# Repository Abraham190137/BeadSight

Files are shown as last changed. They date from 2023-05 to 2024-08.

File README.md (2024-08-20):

# BeadSight
This repo contains the code from the paper, "BeadSight: An Inexpensive Tactile Sensor Using Hydro-Gel Beads"

 - Unet_model.py: Pytorch implementation of the UNet model
 - raw_data_processing.py: Processes the video files, force data, and Gcode commands recorded by recording_main, converting the data into a hdf5 file.
 - model_training.py: Training and Testing of the BeadSight UNet model, using the recorded data.
 - model_eval.py: Functions for running inference on a dataset and printing/plotting the results.
 - inference.py: Code for implementing the trained UNet model (loaded from saved weights) to process images collected during robot operation.
 - defisheye.py: Helper script to undo the fish-eye effect of the bead-sight camera's lens.
 - data_loader.py: Dataset class, along with helper functions, for using the processed beadsight training data.

## Data Collection:
This folder contains all of the code used for data collection and processing. It contains:
 - Arduino code (in the Arduino folder) which was used to collect force data. Scale Data Reader.py is used to control the Arduino over serial link and to save the recorded forces and timestamps.
 - recording_main.py, which records video from the bead sight camera (USB camera), records the current force applied, measured by the Arduino and sent over a serial connection, and controls the 3D printer to execute presses, via commands sent over a serial connection.

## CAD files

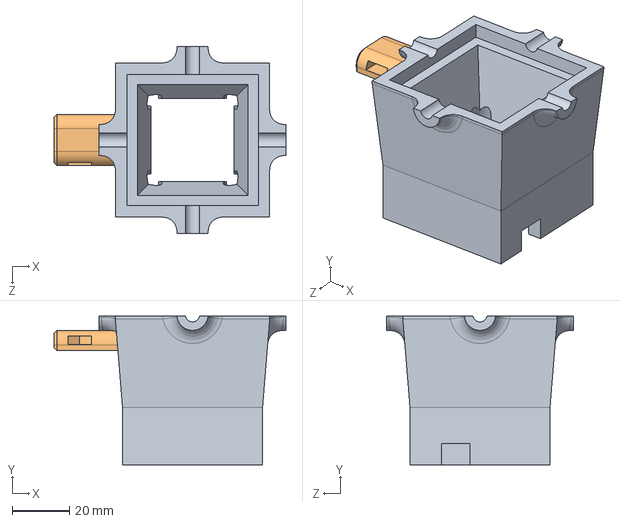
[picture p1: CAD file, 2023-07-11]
SolidWorks/Finger Attachement1.SLDASM
81.2 x 52.0 x 65.4 mm
Sensor Frame Fisheye Acrilic
franka_attachement

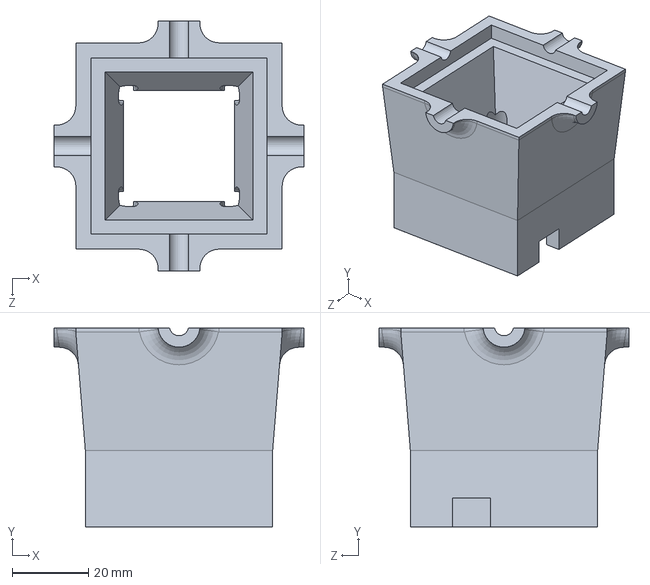
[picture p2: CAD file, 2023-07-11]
SolidWorks/Sensor Frame Fisheye Acrilic.SLDPRT
65.4 x 52.0 x 65.4 mm

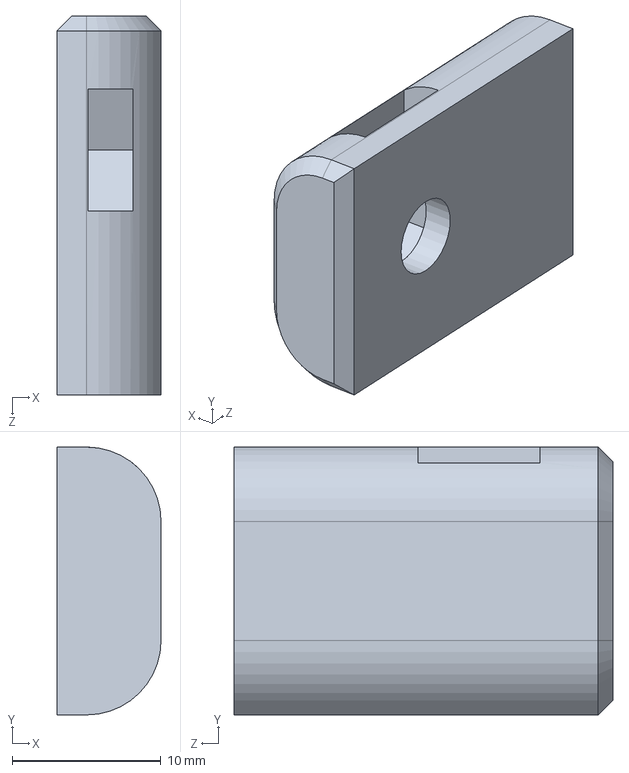
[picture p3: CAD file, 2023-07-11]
SolidWorks/franka_attachement.SLDPRT
7.00 x 18.0 x 25.5 mm

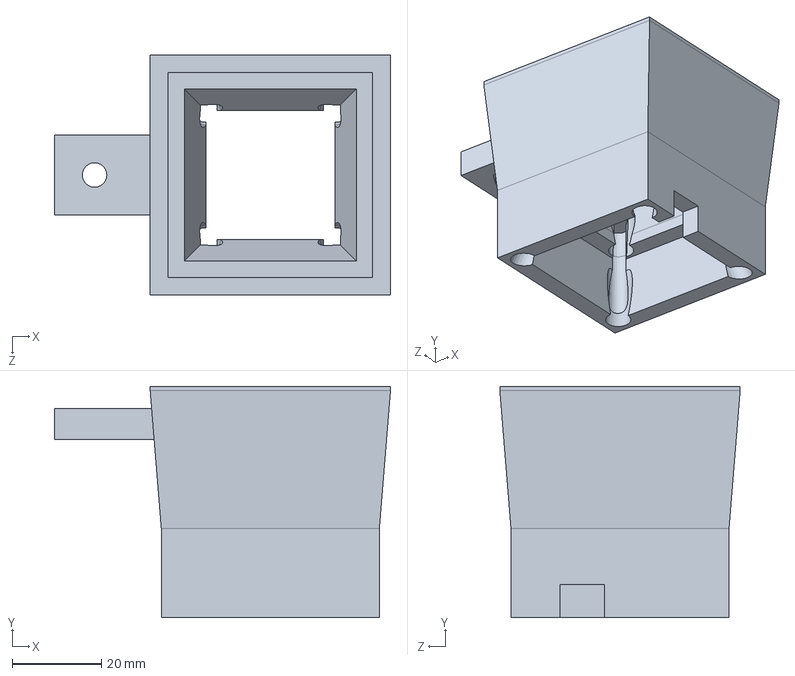
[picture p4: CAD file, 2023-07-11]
SolidWorks/Sensor Frame Fisheye Acrilic No Top Holes, Finger.SLDPRT
75.5 x 52.0 x 54.0 mm

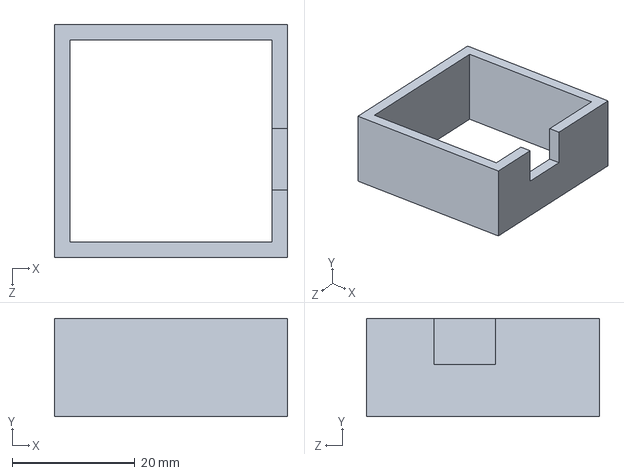
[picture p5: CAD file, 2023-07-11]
SolidWorks/Sensor Camera Holding Piece.SLDPRT
38.0 x 16.0 x 38.0 mm

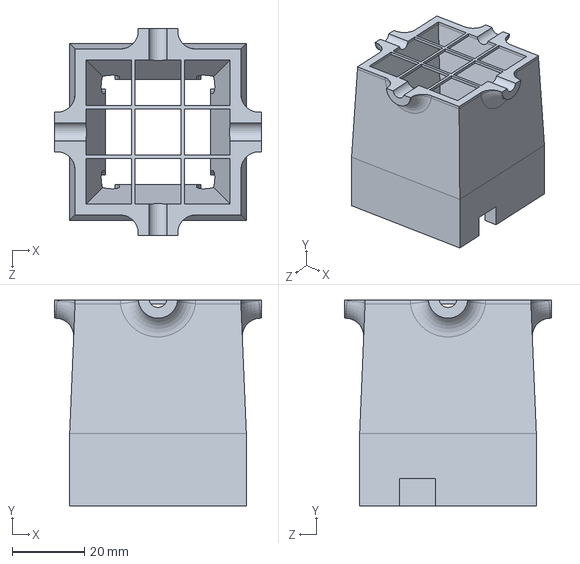
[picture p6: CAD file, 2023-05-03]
SolidWorks/Sensor Frame Fisheye2-40.SLDPRT
57.4 x 57.0 x 57.4 mm

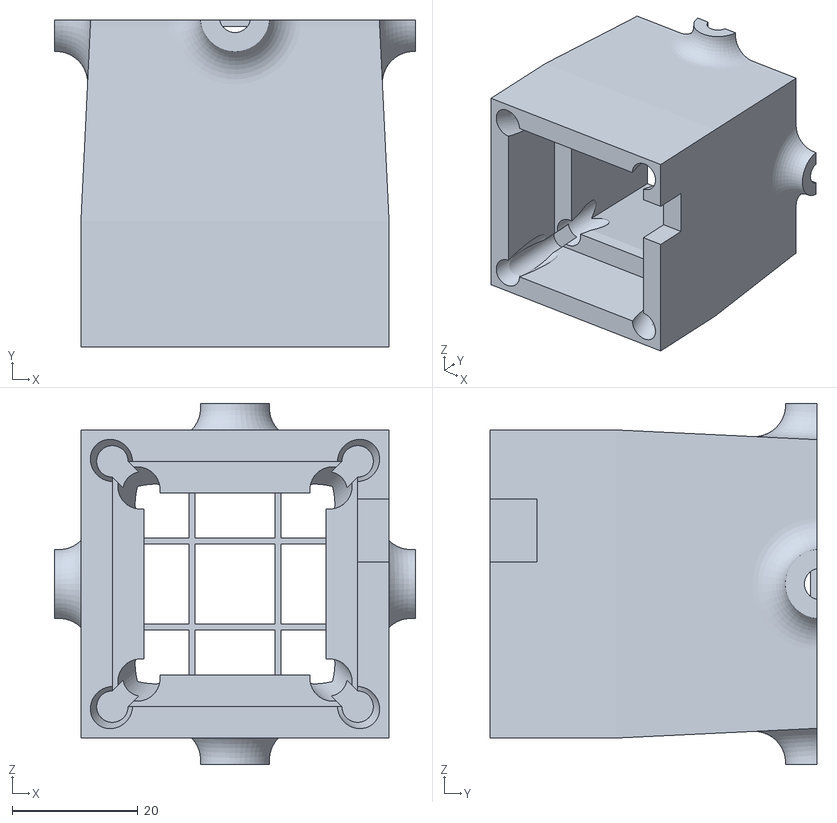
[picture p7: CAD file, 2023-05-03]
SolidWorks/Sensor Frame Fisheye2-35.STL
57.4 x 52.0 x 57.4

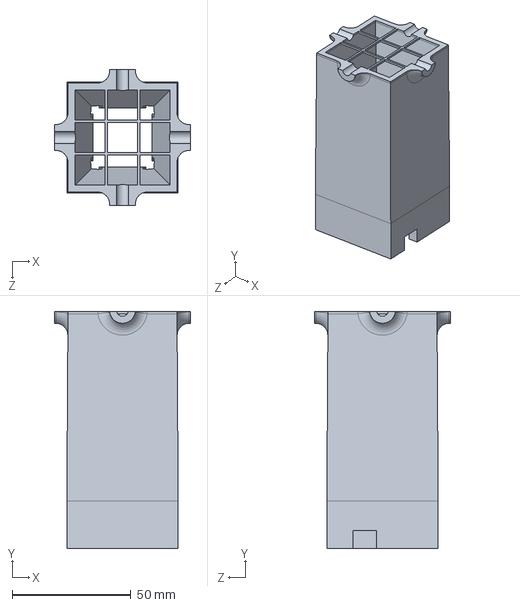
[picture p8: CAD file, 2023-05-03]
SolidWorks/Sensor Frame.SLDPRT
57.4 x 100.0 x 57.4 mm

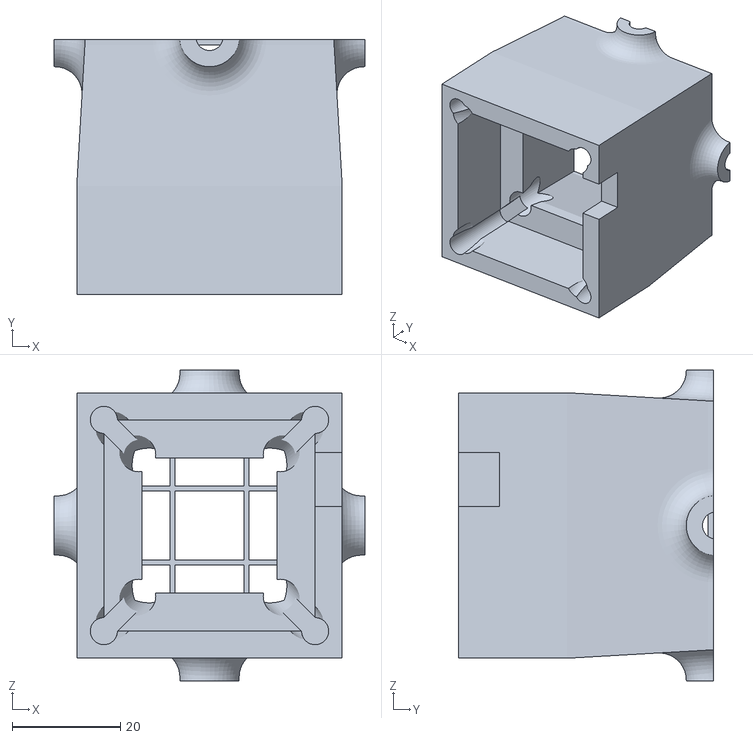
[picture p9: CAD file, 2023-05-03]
SolidWorks/Sensor Frame Fisheye - 30 cm.STL
57.4 x 47.0 x 57.4

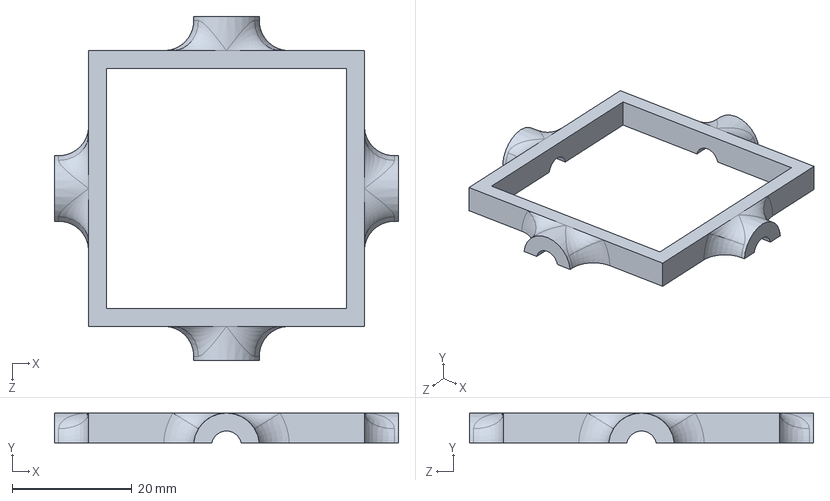
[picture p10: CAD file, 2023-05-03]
SolidWorks/Sensor top.SLDPRT
57.4 x 5.00 x 57.4 mm

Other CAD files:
SolidWorks/Sensor Frame Fisheye.SLDPRT
SolidWorks/Sensor Frame Fisheye2.SLDPRT
SolidWorks/Finger Attachement1.STL
SolidWorks/Sensor Camera Holding Piece.STL
SolidWorks/Sensor Frame Fisheye Acrilic No Top Holes, Finger.STL
SolidWorks/Sensor Frame Fisheye Acrilic.STL
SolidWorks/Sensor Frame Fisheye2-40.STL
SolidWorks/Sensor Frame Fisheye2.STL
SolidWorks/Sensor Frame.STL
SolidWorks/Sensor top.STL
SolidWorks/makeProjectedPlanarWire.x_t

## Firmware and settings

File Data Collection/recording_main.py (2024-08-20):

import cv2
import time
import os
import serial
from typing import List, Tuple
import numpy as np
import multiprocessing
import json


def video_logger(log_folder:str,
                 stop_event: multiprocessing.Event,
                 chunk_size:int=30*60*60, # save a new "chunk" every hour
                 height:int=1024,
                 width:int=1280,
                 fps:int=30,
                 debug_print:bool = False):

    # create the log folder
    frame_number = 0
    video_path = f"{log_folder}/video_{frame_number//chunk_size}.avi"
    log_path = f"{log_folder}/video_log_{frame_number//chunk_size}.txt"

    assert not os.path.exists(video_path), f"File already exists: {video_path}"
    assert not os.path.exists(log_path), f"File already exists: {log_path}"

    fourcc = cv2.VideoWriter_fourcc(*'XVID') # Using XVID codec for AVI format
    video_file = cv2.VideoWriter(video_path, fourcc, fps, (width, height))
    log_file = open(log_path, 'w')

    # Open the webcam
    cap = cv2.VideoCapture(0)

    cap.set(cv2.CAP_PROP_FRAME_WIDTH, width)
    cap.set(cv2.CAP_PROP_FRAME_HEIGHT, height)
    cap.set(cv2.CAP_PROP_FPS, fps)
    cap.set(cv2.CAP_PROP_FOURCC, cv2.VideoWriter_fourcc(*'MJPG'))

    previous_time = time.time()
    start_time = previous_time

    while not stop_event.is_set():
        # Read a frame from the webcam
        ret, frame = cap.read()
        cur_time = time.time()
        if not ret:
            break

        log_file.write(f"{cur_time},{frame_number},{video_path}\n")
        log_file.flush()
        video_file.write(frame)
        frame_number += 1
        
        if debug_print:
            print('\nframe_number:', frame_number)
            print('dt:', cur_time - previous_time)
            print('Avergae FPS:', frame_number / (cur_time - start_time))
            previous_time = cur_time
            print('frame shape:', frame.shape)

        if frame_number % chunk_size == 0:
            # save the video and log files
            video_file.release()
            log_file.close()
            video_path = f"{log_folder}/video_{frame_number//chunk_size}.avi"
            log_path = f"{log_folder}/video_log_{frame_number//chunk_size}.txt"
            assert not os.path.exists(video_path), f"File already exists: {video_path}"
            assert not os.path.exists(log_path), f"File already exists: {log_path}"
            video_file = cv2.VideoWriter(video_path, fourcc, fps, (width, height))
            log_file = open(log_path, 'w')

    # Release the webcam, video file, and log file
    cap.release()
    video_file.release()
    log_file.close()
    print('Video logger stopped successfully')


def force_logger(log_folder:str, 
                 stop_event: multiprocessing.Event,
                 serial_port:str = '/dev/ttyACM0'):

    assert os.path.exists(log_folder), f"Folder does not exist: {log_folder}"
    log_file = open(f"{log_folder}/force_log.txt", 'w') 
    last_read_time = time.time()   

    with serial.Serial(serial_port, 57600, timeout=2) as ser:
        start = False
        while not stop_event.is_set():
            if time.time()-last_read_time > 10:
                raise ValueError("No data read in 10 seconds")
            line = ser.readline()   # read a '\n' terminated line
            try:
                measurement = float(line.decode()[:-1])
            except:
                print("Error reading line:", line)
                continue
            cur_time = time.time()
            last_read_time = cur_time
            log_file.write(f"{cur_time},{measurement}\n")
            log_file.flush()
            
    log_file.close()
    print('Force logger stopped successfully')


class PrinterControl:
    def __init__(self, log_folder:str, serial_port:str) -> None:
        self.log_folder = log_folder
        self.log_file = open(f"{log_folder}/printer_log.txt", 'w')
        self.ser = serial.Serial(serial_port, 115200) 
        self.closed = False

    def send_command(self, command:str, rec_x:float=-1, rec_y:float=-1, delay:float=1):
        self.ser.write((command + "\n").encode())
        print(command)
        cur_time = time.time()
        self.log_file.write(f"{cur_time},{rec_x},{rec_y},{command}\r") # need to use \r, because the command can contain \n
        self.log_file.flush()
        time.sleep(delay)

    def close(self):
        self.ser.close()
        self.log_file.close()
        self.closed = True

    def __del__(self):
        if not self.closed:
            self.close()

# message for one press action
def press_message(x_loc: float, y_loc: float, z_down:float, z_up:float):
    return f"G0 X{x_loc} Y{y_loc} Z{z_up} F700; move to position\n" + \
           f"G0 X{x_loc} Y{y_loc} Z{z_down} F200; press\n" + \
           "G04 P1000; pause\n" + \
           f"G0 X{x_loc} Y{y_loc} Z{z_up} F700; release"

def run_exeriment(log_folder:str, 
                  run_time:float,
                  x_range:Tuple[float, float],
                  y_range:Tuple[float, float],
                  z_range:Tuple[float, float],
                  z_clear:float = 160):

    # initalize the loggers:
    stop_event = multiprocessing.Event()
    video_logger_process = multiprocessing.Process(target=video_logger, args=(log_folder, stop_event), daemon=True)
    video_logger_process.start()
    force_logger_process = multiprocessing.Process(target=force_logger, args=(log_folder, stop_event), daemon=True)
    force_logger_process.start()
    printer = PrinterControl(log_folder, '/dev/ttyUSB0')

    try:
        # initalize the printer:
        printer.send_command("M140 S0 T0; set temp of bed", delay = 1)
        printer.send_command("M104 S0 T0; set temp of extruder 1", delay = 1)
        printer.send_command("M104 S0 T1; set temp of extruder 2", delay = 1)
        printer.send_command("G90; use absolute positioning", delay = 1)
        printer.send_command("G28; home all axes", delay = 45)
        printer.send_command(f"G0 X0 Y0 Z{z_clear} F700; move to clear position", delay = 30)
        printer.send_command(f"G0 X{x_range[0]-10} Y{y_range[0]-10} Z{z_clear} F700; calibration motion", delay = 30)

        calib_offset = 10
        # Calibaration presses:
        for x_pos, y_pos in [(x_range[0]-calib_offset, y_range[0]-calib_offset), (x_range[0]-calib_offset, y_range[1]+calib_offset), (x_range[1]+calib_offset, y_range[0]-calib_offset), (x_range[1]+calib_offset, y_range[1]+calib_offset)]:
            printer.send_command(press_message(x_pos, y_pos, z_range[0], z_clear), -1, -1, 15)

        for x_pos, y_pos in [(x_range[0], y_range[0]), (x_range[0], y_range[1]), (x_range[1], y_range[0]), (x_range[1], y_range[1])]:
            printer.send_command(press_message(x_pos, y_pos, z_range[0], z_clear), -1, -1, 15)

        # begin the real testing:
        start_time = time.time()
        press_num = 0
        while time.time() - start_time < run_time:
            x_pos = np.random.uniform(x_range[0], x_range[1])
            y_pos = np.random.uniform(y_range[0], y_range[1])
            z_pos = np.random.uniform(z_range[0], z_range[1])

            printer.send_command(press_message(x_pos, y_pos, z_pos, z_clear), x_pos, y_pos, 10)

        print("Experiment completed successfully")

    except:
        print("An error occured, stopping the experiment")

    stop_event.set()
    video_logger_process.join()
    force_logger_process.join()
    printer.close()

if __name__ == "__main__":
    save_dir = "Data Collection/data"
    save_name = "5 hr data collection - 100 my bag"
    run_time = 5*60*60 # number of seconds to run for.
    center = (151.8, 108.9)
    radius = 13.75
    x_range = (center[0] - radius, center[0] + radius)
    y_range = (center[1] - radius, center[1] + radius)
    z_range = (127, 128)
    z_clear = 137.5

    n = 0
    while os.path.exists(f"{save_dir}/{save_name}_{n}"):
        n += 1
    folder_name = f"{save_dir}/{save_name}_{n}"
    os.mkdir(folder_name)

    # save parametes in json file:
    meta_data = {
        "resolution": (256, 256),
        "fps": 30,
        "contact_radius": 6.25,
        "sensor_size": (41, 41),
        "force_unit": "g",
        "dist_unit": "mm",
        "run_time": run_time,
        "center": center,
        "radius": radius,
        "x_range": x_range, 
        "y_range": y_range, 
        "z_range": z_range, 
        "z_clear": z_clear
    }

    with open(f"{folder_name}/experiment_parameters.json", 'w') as f:
        json.dump(meta_data, f)

    run_exeriment(log_folder=folder_name,
                  run_time=run_time,
                  x_range=x_range,
                  y_range=y_range,
                  z_range=z_range,
                  z_clear=z_clear)
    

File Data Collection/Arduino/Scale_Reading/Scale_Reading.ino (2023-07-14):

/**
 * Complete project details at https://RandomNerdTutorials.com/arduino-load-cell-hx711/
 *
 * HX711 library for Arduino - example file
 * https://github.com/bogde/HX711
 *
 * MIT License
 * (c) 2018 Bogdan Necula
 *
**/

#include <Arduino.h>
#include "HX711.h"

// HX711 circuit wiring
const int LOADCELL_DOUT_PIN = 2;
const int LOADCELL_SCK_PIN = 3;
const float calibration = 465.0;

HX711 scale;

void setup() {
  pinMode(7, OUTPUT); 
  Serial.begin(57600);
  // Serial.println("HX711 Demo");
  // Serial.println("Initializing the scale");

  scale.begin(LOADCELL_DOUT_PIN, LOADCELL_SCK_PIN);

  // Serial.println("Before setting up the scale:");
  // Serial.print("read: \t\t");
  // Serial.println(scale.read());      // print a raw reading from the ADC

  // Serial.print("read average: \t\t");
  // Serial.println(scale.read_average(20));   // print the average of 20 readings from the ADC

  // Serial.print("get value: \t\t");
  // Serial.println(scale.get_value(5));   // print the average of 5 readings from the ADC minus the tare weight (not set yet)

  // Serial.print("get units: \t\t");
  // Serial.println(scale.get_units(5), 1);  // print the average of 5 readings from the ADC minus tare weight (not set) divided
  //           // by the SCALE parameter (not set yet)
            
  scale.set_scale(calibration);    // this value is obtained by calibrating the scale with known weights; see the README for details
  scale.tare();               // reset the scale to 0

  // Serial.println("After setting up the scale:");

  // Serial.print("read: \t\t");
  // Serial.println(scale.read());                 // print a raw reading from the ADC

  // Serial.print("read average: \t\t");
  // Serial.println(scale.read_average(20));       // print the average of 20 readings from the ADC

  // Serial.print("get value: \t\t");
  // Serial.println(scale.get_value(5));   // print the average of 5 readings from the ADC minus the tare weight, set with tare()

  // Serial.print("get units: \t\t");
  // Serial.println(scale.get_units(5), 1);        // print the average of 5 readings from the ADC minus tare weight, divided
  //           // by the SCALE parameter set with set_scale

  // Serial.println("Readings:");
  digitalWrite(7, HIGH);
  Serial.println("start");
  delay(500);
  digitalWrite(7, LOW);
}
int i = 0;
double reading;
void loop() {
  // Serial.print("one reading:\t");
  // Serial.print(scale.get_units(), 1);
  reading = (double)scale.get_units();
  reading += 10000.0*(double)i;
  Serial.println(reading, 2);
  // Serial.println(i);
  // Serial.print("\t| average:\t");
  // Serial.println(scale.get_units(10), 5);
  i = (i+1)%10;
  delay(10);
}

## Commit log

2023-04-06 added data processing
    [test_info_file.csv, testing Gcode 4-5.g]
2023-05-03 Uploaded Solidworks files
    [Sensor Frame Fisheye - 30 cm.STL, Sensor Frame Fisheye Acrilic.SLDPRT, Sensor Frame Fisheye Acrilic.STL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]
2023-07-11 new solidworks stuff
    [Finger Attachement1.SLDASM, Finger Attachement1.STL, Sensor Camera Holding Piece.SLDPRT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]
2023-07-14 Fixed initial processing
    [data_collection_2.g, test_info_file.csv, testing Gcode 4-5.g]
2023-07-14 updated data processing to fix the distance between peaks issue
    [Data Processing.py]
2024-04-05 Atharva - Uploaded all my work for Tactile Sensors
2024-08-20 added printer and scale tests
